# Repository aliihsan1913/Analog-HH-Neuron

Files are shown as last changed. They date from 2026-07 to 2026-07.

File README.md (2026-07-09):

# Analog Hardware Simulation of the Hodgkin-Huxley Neuron Model

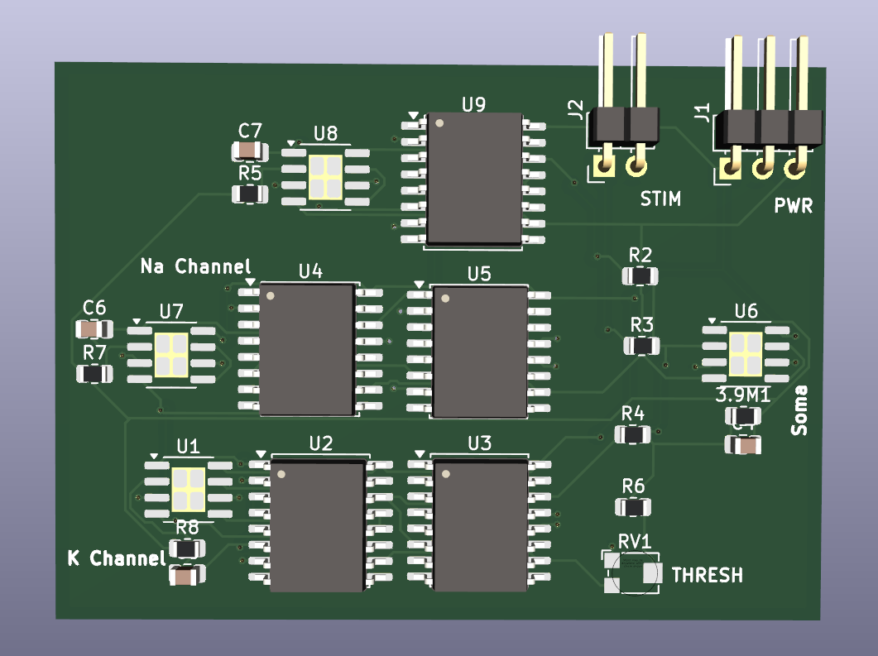
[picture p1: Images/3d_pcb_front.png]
3D PCB Render


## 1. Project Overview and Purpose
This repository contains the design, simulation, and manufacturing files for an analog computational hardware that physically models the Hodgkin-Huxley (HH) biological neuron. The primary objective is to transition neuro-biophysical concepts from theoretical mathematics into a tangible engineering prototype.

Instead of utilizing microprocessors or algorithmic software to approximate the differential equations, this circuit solves the time and voltage-dependent variables ($V, m, h, n$) in real-time using the inherent physical properties of electrons, capacitors, and non-linear analog multipliers. 

## 2. Biological Reference and Parameter Extraction
The electronic component values in this design are strictly derived from the morphological data of a real biological cell, utilizing foundational physics principles rather than hypothetical values.

* **Reference Neuron:** 1-10-8 (Rat, Neocortex)
* **Soma Surface Area:** 1147.99 µm² ($A \approx 1.15 \times 10^{-5}\ cm^{2}$)
* **Data Source:** NeuroMorpho Database

By multiplying the universal specific membrane capacitance ($1\ \mu F / cm^{2}$) and specific channel conductances by the actual surface area of the 1-10-8 neuron, the following hardware parameters were calculated and implemented in the circuit:
* **Soma Membrane Capacitance:** $\approx 11.5\ pF$
* **Sodium (Na) Channel Resistance:** $\approx 724\ k\Omega$
* **Potassium (K) Channel Resistance:** $\approx 2.41\ M\Omega$

## 3. Hardware Architecture
The system is designed on a 2-layer Printed Circuit Board (PCB) using KiCad, featuring an unbroken ground plane on the bottom layer to ensure signal integrity for the analog pathways. Trace widths are constrained to 0.25 mm with 0.20 mm clearances to accommodate the dense IC placement.

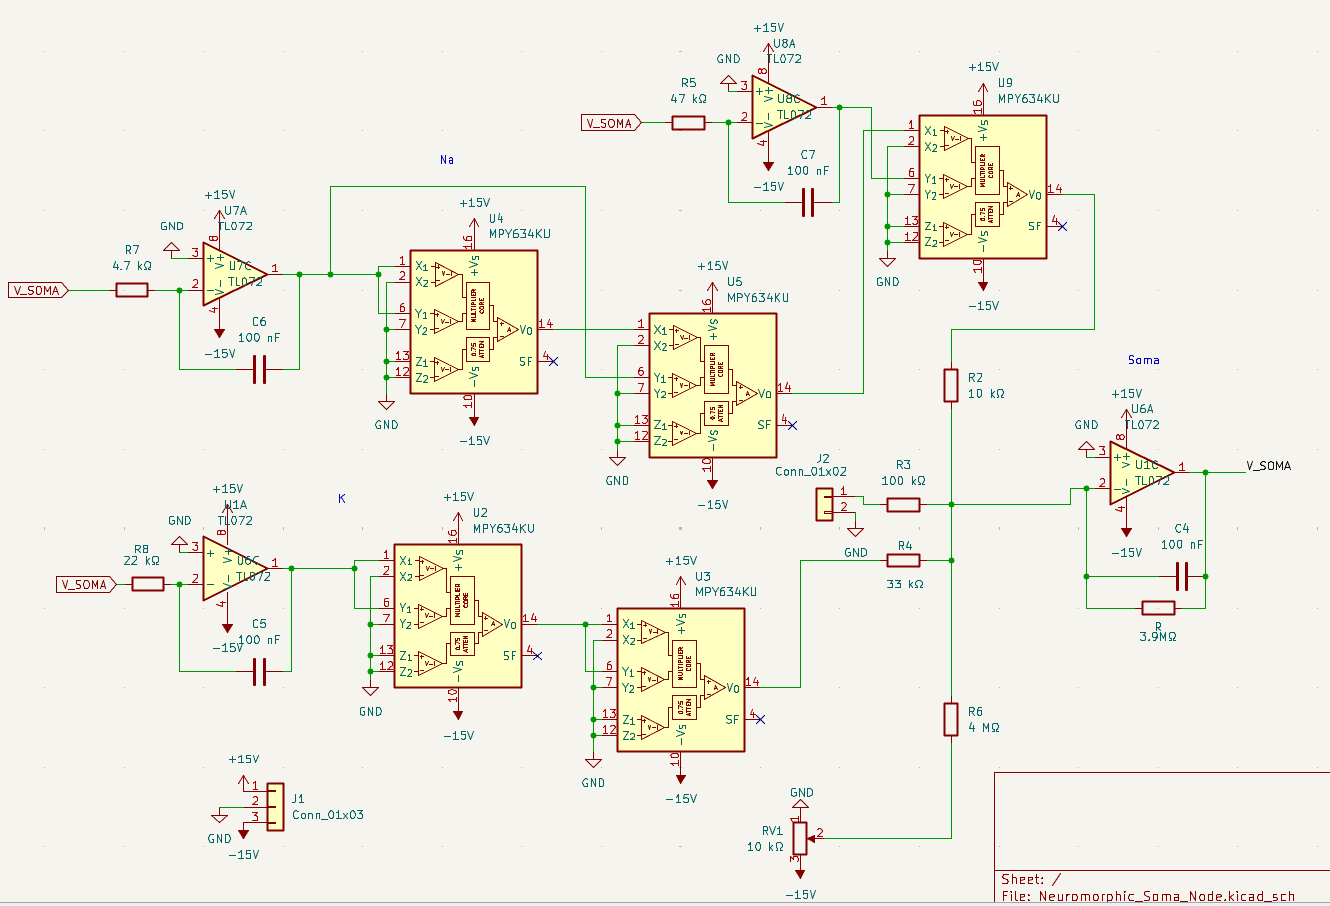
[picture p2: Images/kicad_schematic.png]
KiCad Schematic


The architecture is divided into three core functional blocks:
* **Soma:** Represented by the central capacitor. The accumulation and discharge of charge on this component physically represent the resting potential and action potentials (spikes).
* **Voltage-Controlled Channels:** Built using TL072 operational amplifiers (acting as integrators for gating variables) and MPY634 precision analog multipliers. The multipliers physically execute the non-linear conductance equations (e.g., $m^3h$ for Na and $n^4$ for K).
* **Stimulus (STIM) and Threshold (THRESH):** External input ports for injecting nanoampere-level synaptic currents and a leakage resistor network to maintain the resting potential at approximately -65 mV.

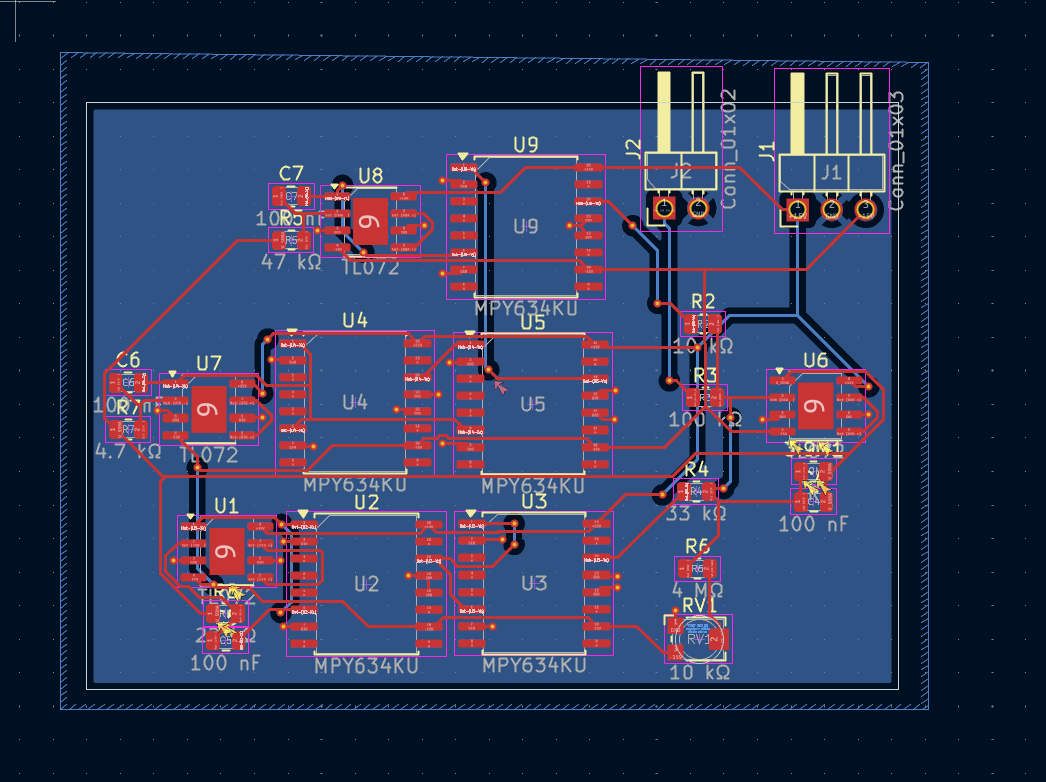
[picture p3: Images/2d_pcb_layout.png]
2D PCB Layout


## 4. Simulation and Ground Truth
Prior to hardware manufacturing, the extracted parameters were simulated in two distinct environments to verify the mathematical model against the electronic implementation.

### Mathematical Ground Truth (Python/SciPy)
The standard HH differential equations were solved using numerical integration to establish the baseline biological response. Under a 0.2 nA stimulus, the mathematical model exhibits precise spiking behavior.

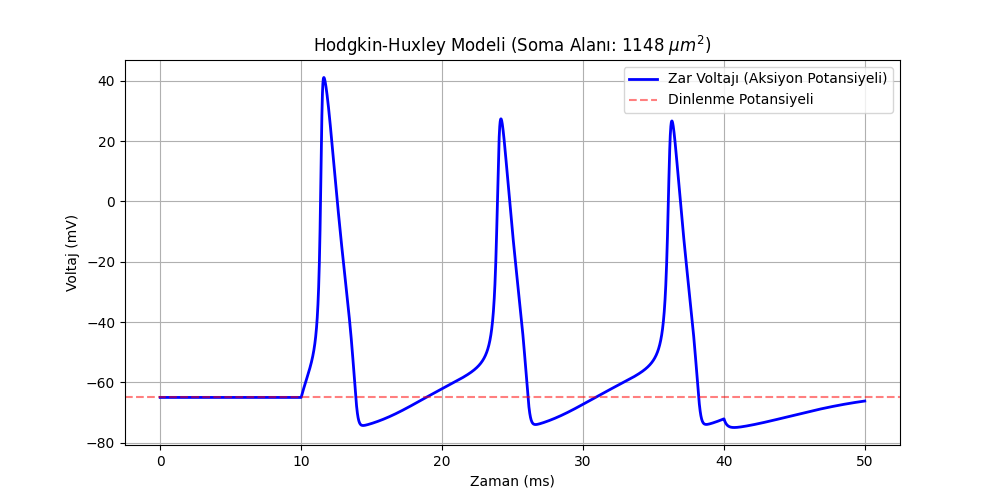
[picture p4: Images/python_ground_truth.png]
Python Ground Truth


### Analog Circuit Simulation (LTspice)
The physical hardware schematic was simulated in LTspice. The resulting transient analysis waveforms confirm that the analog components successfully replicate the action potentials, matching the mathematical ground truth and proving the viability of the physical circuit.

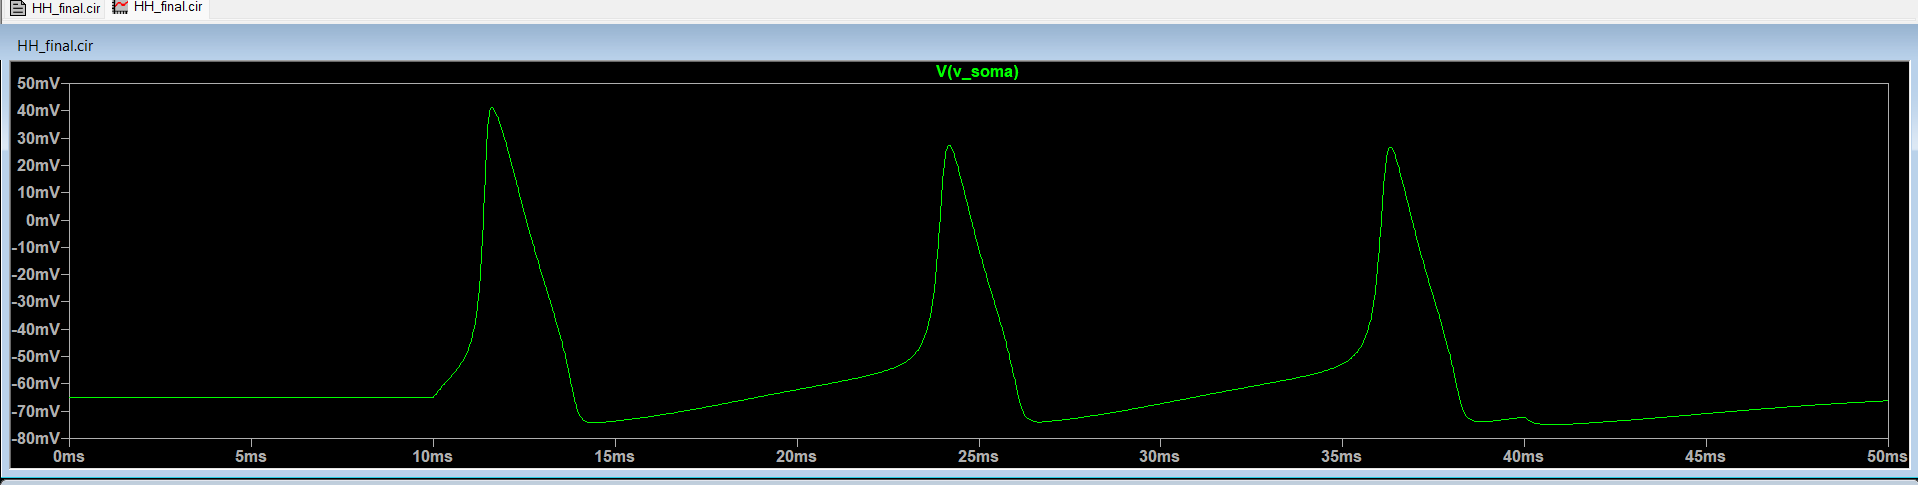
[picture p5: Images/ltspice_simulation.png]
LTspice Simulation


## 5. Repository Structure
* `/hardware`: Contains KiCad PCB design files and LTspice simulation models.
* `/simulation`: Contains the Python script (`hh_model.py`) for the numerical ground truth.
* `/images`: Renderings and plots used in this documentation.
* `1-10-8_Neuromorpho.md`: Detailed mathematical proofs and parameter conversion calculations.

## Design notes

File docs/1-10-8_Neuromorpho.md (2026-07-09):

# Biological Reference and Hardware Parameters: Neuron 1-10-8

This project aims to transform the theoretical Hodgkin-Huxley (HH) neuron model into a physical analog computer hardware. None of the capacitor or resistor values in the designed electronic circuit are hypothetical; all of them are derived from the morphological data of a real biological cell using fundamental principles of physics.

## 1. Reference Biological Neuron Data
The neuron named **1-10-8** from the NeuroMorpho database was selected for the simulation and hardware design.

* **Neuron Name:** 1-10-8
* **Species:** Rat
* **Region:** Neocortex
* **Soma Surface Area:** 1147.99 µm²
* **Original Data Source (Link):** [https://neuromorpho.org/neuron_info.jsp?neuron_name=1-10-8](https://neuromorpho.org/neuron_info.jsp?neuron_name=1-10-8)

---

## 2. Conversion from Biological Data to Electronic Values (Mathematical Proof)

Specific cell membrane parameters, measured by biophysicists and universally accepted in literature, were multiplied by the surface area ($A$) obtained from NeuroMorpho to derive specific electronic component values (Farads and Ohms).

Converting the 1147.99 µm² soma area to square centimeters:
$$A \approx 1.15 \times 10^{-5}\ cm^{2}$$

### A. Cell Membrane Capacitance Calculation
The cell membrane (lipid bilayer) acts as an insulating barrier between conductive ionic fluids, naturally behaving like a parallel-plate capacitor. The capacitance of 1 cm² of membrane is universally accepted as $C_{m} = 1\ \mu F / cm^{2}$.

The actual capacitor equivalent of the 1-10-8 neuron in the circuit is calculated as follows:
$$C_{total} = C_{m} \times A$$
$$C_{total} = (1\ \mu F / cm^{2}) \times (1.15 \times 10^{-5}\ cm^{2})$$
**Hardware Equivalent (Soma Capacitor):** $\approx 11.5\ pF$

### B. Ion Channel Conductance and Resistance Calculations
In the Hodgkin-Huxley model, the maximum sodium ($Na$) and potassium ($K$) conductances per 1 cm² are specific constants. These conductances ($G$) were calculated, and their inverses ($R = \frac{1}{G}$) were taken to obtain the resistor values to be used in the hardware.

**Sodium (Na) Channel:**
Standard $Na$ conductance: $120\ mS / cm^{2}$
$$G_{Na} = (120\ mS / cm^{2}) \times (1.15 \times 10^{-5}\ cm^{2}) \approx 1.38 \times 10^{-3}\ mS$$
$$R_{Na} = \frac{1}{G_{Na}}$$
**Hardware Equivalent ($Na$ Channel Resistance):** $\approx 724\ k\Omega$

**Potassium (K) Channel:**
Standard $K$ conductance: $36\ mS / cm^{2}$
$$G_{K} = (36\ mS / cm^{2}) \times (1.15 \times 10^{-5}\ cm^{2}) \approx 4.14 \times 10^{-4}\ mS$$
$$R_{K} = \frac{1}{G_{K}}$$
**Hardware Equivalent ($K$ Channel Resistance):** $\approx 2.41\ M\Omega$

**Leakage (Threshold) Channel:**
Standard leakage conductance: $0.3\ mS / cm^{2}$
$$G_{L} = (0.3\ mS / cm^{2}) \times (1.15 \times 10^{-5}\ cm^{2}) \approx 3.45 \times 10^{-6}\ mS$$
$$R_{L} = \frac{1}{G_{L}}$$
**Hardware Equivalent (Threshold Setting Resistor):** $\approx 289\ M\Omega$

---

## 3. Analog Hardware Architecture and Mapping

These calculated physical values were mapped to the following hardware blocks on the PCB:

* **Soma (Central Processing):** The capacitor acting as the cell membrane. Biological charge and discharge events occur directly on this component.
* **Voltage-Controlled Channels (TL072 and MPY634):** An active control circuit that integrates the non-linear opening and closing rates ($m, h, n$ variables) of Sodium and Potassium gates with time constants and multiplies them analogously. The $m^3h$ and $n^4$ functions are physically solved by MPY634 multiplier ICs.
* **STIM (Stimulus) and THRESH (Threshold):** The nanoampere-level current input applying external synaptic pressure to the circuit, and the leakage mechanism allowing the system to maintain its resting voltage (-65 mV).

Through this architecture, without using any software "If-Else" logic, time and voltage equations are solved in real-time directly by the laws of physics and analog electronics.

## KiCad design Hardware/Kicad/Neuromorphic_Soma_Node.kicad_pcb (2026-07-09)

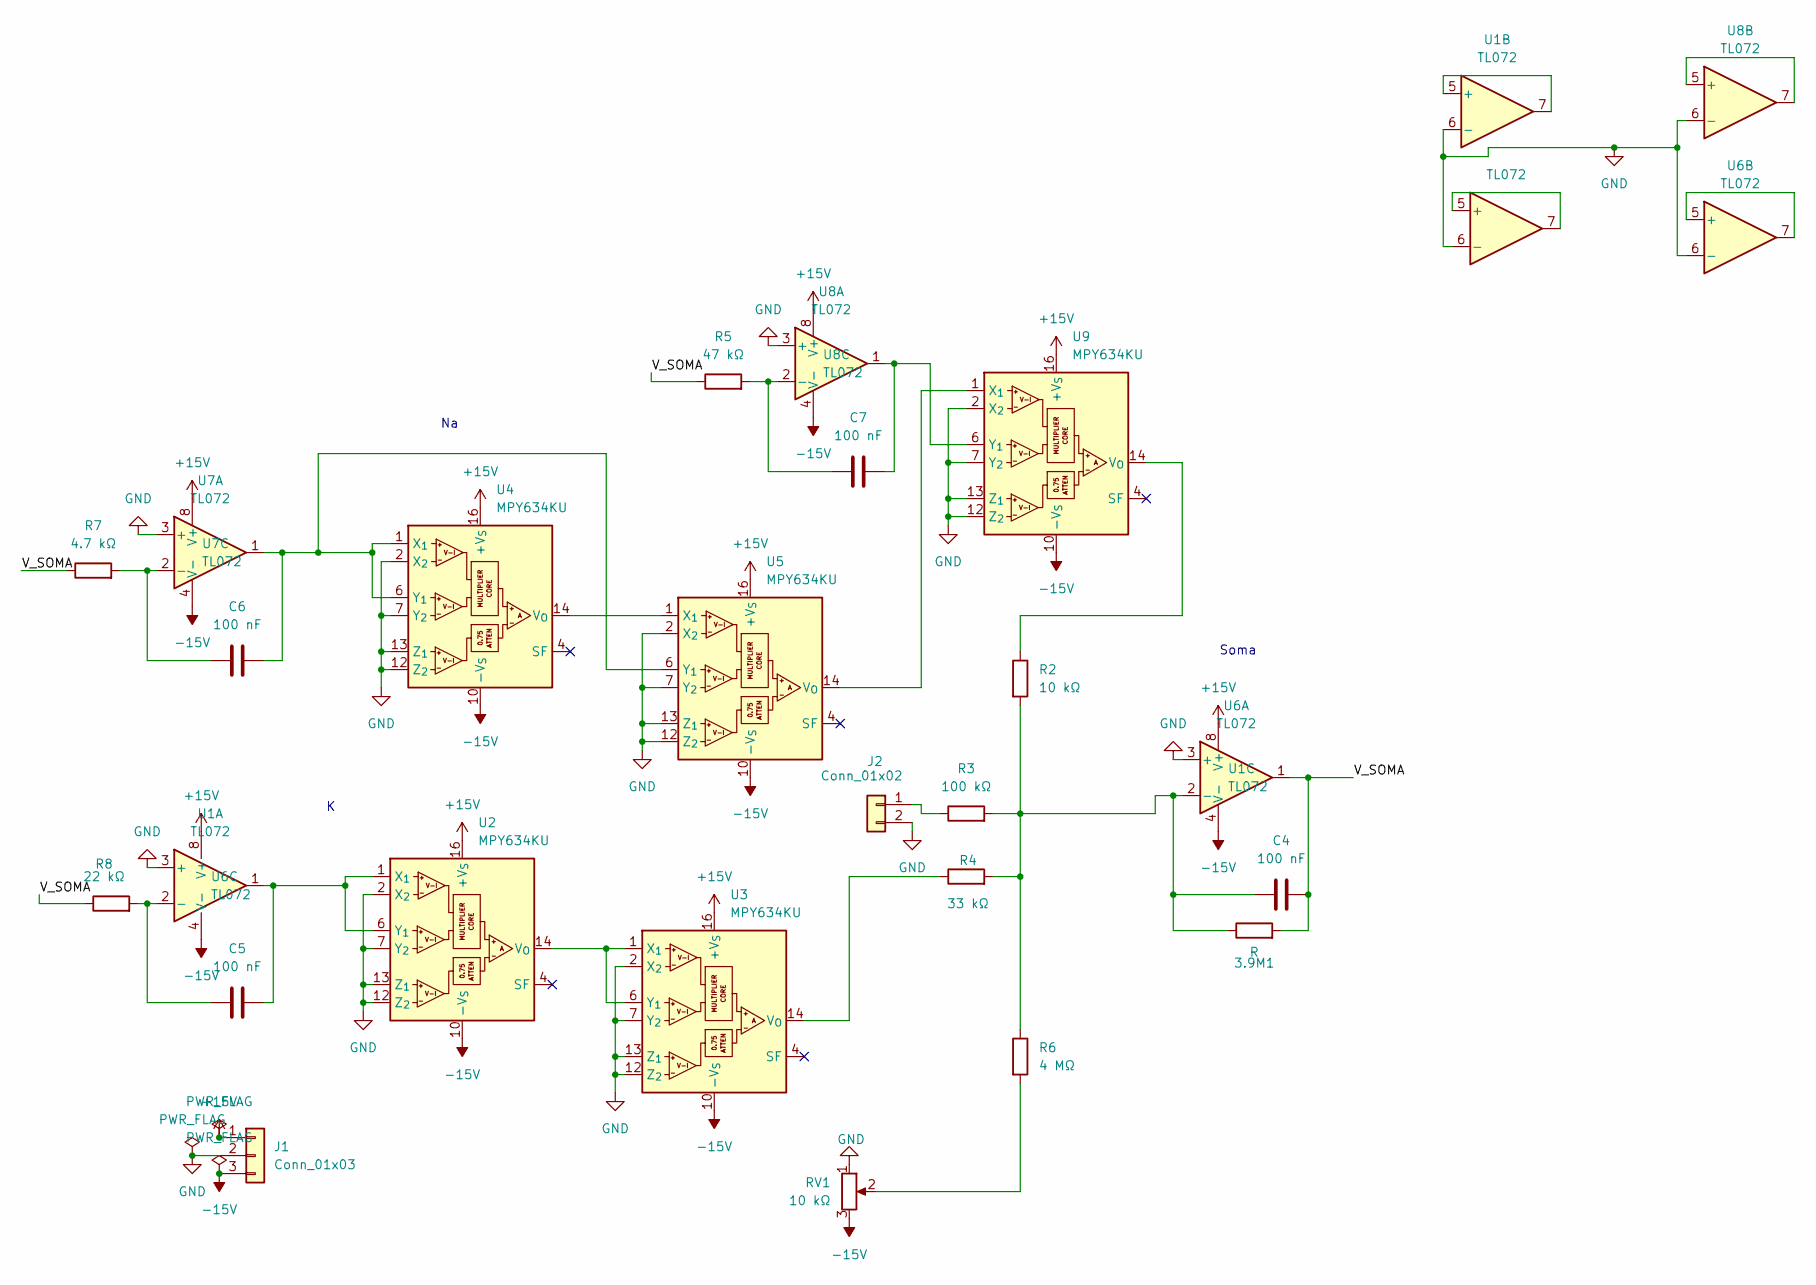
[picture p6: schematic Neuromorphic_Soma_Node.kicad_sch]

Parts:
3.9M1: R; R_0805_2012Metric
C4, C5, C6, C7: 100 nF; C_0805_2012Metric
J1: Conn_01x03; PinHeader_1x03_P2.54mm_Horizontal
J2: Conn_01x02; PinHeader_1x02_P2.54mm_Horizontal
R2: 10 kΩ; R_0805_2012Metric
R3: 100 kΩ; R_0805_2012Metric
R4: 33 kΩ; R_0805_2012Metric
R5: 47 kΩ; R_0805_2012Metric
R6: 4 MΩ; R_0805_2012Metric
R7: 4.7 kΩ; R_0805_2012Metric
R8: 22 kΩ; R_0805_2012Metric
RV1: 10 kΩ; Potentiometer_Bourns_TC33X_Vertical
U1, U6, U7, U8: TL072; SOIC-8-1EP_3.9x4.9mm_P1.27mm_EP2.62x3.51mm
U2, U3, U4, U5, U9: MPY634KU; SOIC-16W_7.5x10.3mm_P1.27mm

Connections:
+15V: J1.1, U1.8 (V+), U2.16 (+V_{S}), U3.16 (+V_{S}), U4.16 (+V_{S}), U5.16 (+V_{S}), U6.8 (V+), U7.8 (V+), U8.8 (V+), U9.16 (+V_{S})
-15V: J1.3, RV1.3, U1.4 (V-), U2.10 (-V_{S}), U3.10 (-V_{S}), U4.10 (-V_{S}), U5.10 (-V_{S}), U6.4 (V-), U7.4 (V-), U8.4 (V-), U9.10 (-V_{S})
/V_SOMA: 3.9M1.2, C4.2, R5.1, R7.1, R8.1, U6.1
GND: J1.2, J2.2, RV1.1, U1.3 (+), U1.6 (-), U2.2 (X_{2}), U2.7 (Y_{2}), U2.12 (Z_{2}), U2.13 (Z_{1}), U3.2 (X_{2}), U3.7 (Y_{2}), U3.12 (Z_{2}), U3.13 (Z_{1}), U4.2 (X_{2}), U4.7 (Y_{2}), U4.12 (Z_{2}), U4.13 (Z_{1}), U5.2 (X_{2}), U5.7 (Y_{2}), U5.12 (Z_{2}), U5.13 (Z_{1}), U6.3 (+), U6.6 (-), U7.3 (+), U7.6 (-), U8.3 (+), U8.6 (-), U9.2 (X_{2}), U9.7 (Y_{2}), U9.12 (Z_{2}), U9.13 (Z_{1})
unnamed: J2.1, R3.1
unnamed: R6.2, RV1.2
unnamed: C5.1, R8.2, U1.2 (-)
unnamed: U1.5 (+), U1.7
unnamed: U2.14 (V_{O}), U3.1 (X_{1}), U3.6 (Y_{1})
unnamed: C5.2, U1.1, U2.1 (X_{1}), U2.6 (Y_{1})
unnamed: R4.1, U3.14 (V_{O})
unnamed: U4.14 (V_{O}), U5.1 (X_{1})
unnamed: C6.2, U4.1 (X_{1}), U4.6 (Y_{1}), U5.6 (Y_{1}), U7.1
unnamed: U5.14 (V_{O}), U9.1 (X_{1})
unnamed: 3.9M1.1, C4.1, R2.2, R3.2, R4.2, R6.1, U6.2 (-)
unnamed: U6.5 (+), U6.7
unnamed: C6.1, R7.2, U7.2 (-)
unnamed: U7.5 (+), U7.7
unnamed: C7.1, R5.2, U8.2 (-)
unnamed: U8.5 (+), U8.7
unnamed: R2.1, U9.14 (V_{O})
unnamed: C7.2, U8.1, U9.6 (Y_{1})

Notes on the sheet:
Soma

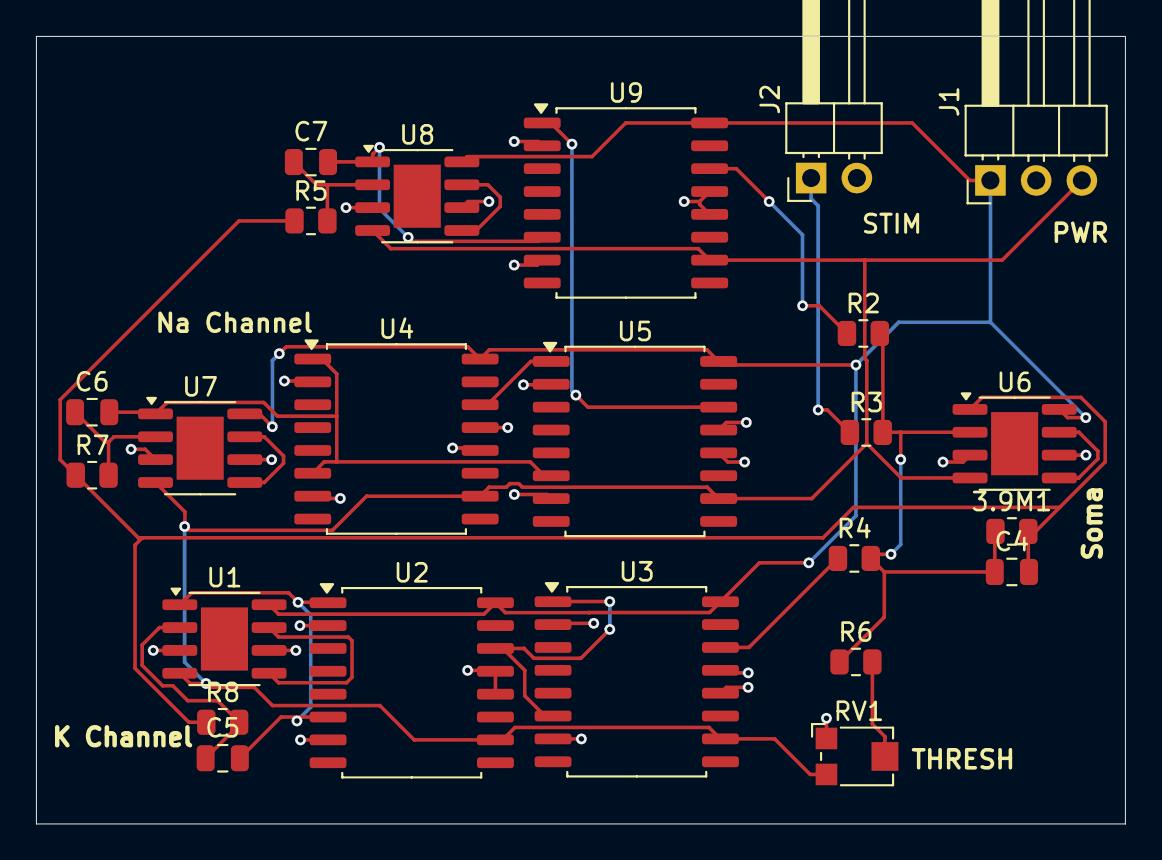
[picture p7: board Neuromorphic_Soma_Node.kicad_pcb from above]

Board: 2 copper layers, 60.5 x 43.8 mm, 24 parts (0 on the bottom side), 22 nets.
